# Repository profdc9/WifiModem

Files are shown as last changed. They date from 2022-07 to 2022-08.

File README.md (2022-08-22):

# WiFi Modem

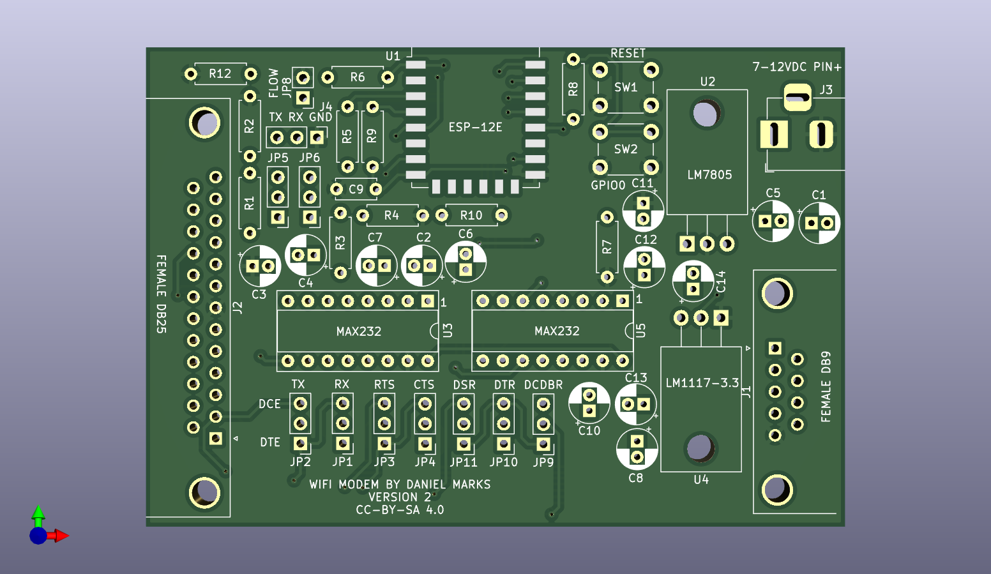
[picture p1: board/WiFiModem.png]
WiFiModem


This is a simple layout for connection a ESP12E to a serial port so that a serial to wireless gateway can be used.  It connects RTS/CTS for flow control (when supported) and has DB9 female/male and DB25 female/male connectors.  The particular gender of the connector can be mounted on the side of the board indicated by the silkscreening.  DB25 male is used to connect directly to an Apple Super Serial Card.  DB25 female is the standard connection of old-style dialup modems.  There are jumpers that swap TXD/RXD, RTS/CTS, and DTR/DSR to implement a built-in null modem changer.

There are several types of firmware that could be used on it.

https://github.com/jeelabs/esp-link

ESP Link is a firmware that enables remote access to a microcontroller or serial port through a web page or TCP port.

https://github.com/dhansel/WifiModem

https://github.com/jsalin/esp8266_modem

https://github.com/maccasoft/WifiModem/blob/master/WifiModem.ino

https://github.com/ssshake/vintage-computer-wifi-modem

https://github.com/stardot/esp8266_modem/wiki

https://github.com/RolandJuno/esp8266_modem    (implements CTS)

https://github.com/bozimmerman/Zimodem

A firmware image "zimodem.ino.nodemcu-3.4.bin" may be downloaded from:

http://subethasoftware.com/files/zimodem/

For using with ZiModem, use the following settings:

```
ATS47=5
OK
ATS49=15
OK
ATS51=13
OK
ATS53=12
OK
ATS55=14
OK
ATS57=4
OK
ATB9600
OK
AT&W
```
(default baud rate 9600 for example)

If you use the Zimodem firmware (current version 3.7.0 in that directory) that is in the "zimodem-firmware" directory, it is already compiled to point DTR/DSR/RI/RTS/CTS to the correct GPIO pins.  The default baud rate is 1200.  You can use esptool.py or the flash download tool to load it to the address 0x0000.

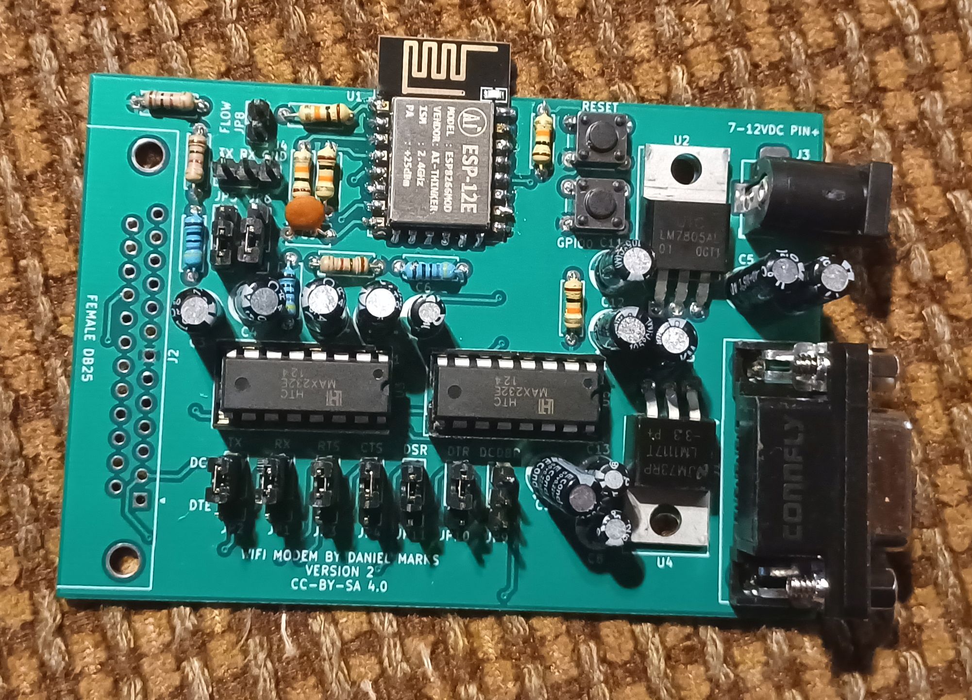
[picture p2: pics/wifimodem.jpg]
PCB


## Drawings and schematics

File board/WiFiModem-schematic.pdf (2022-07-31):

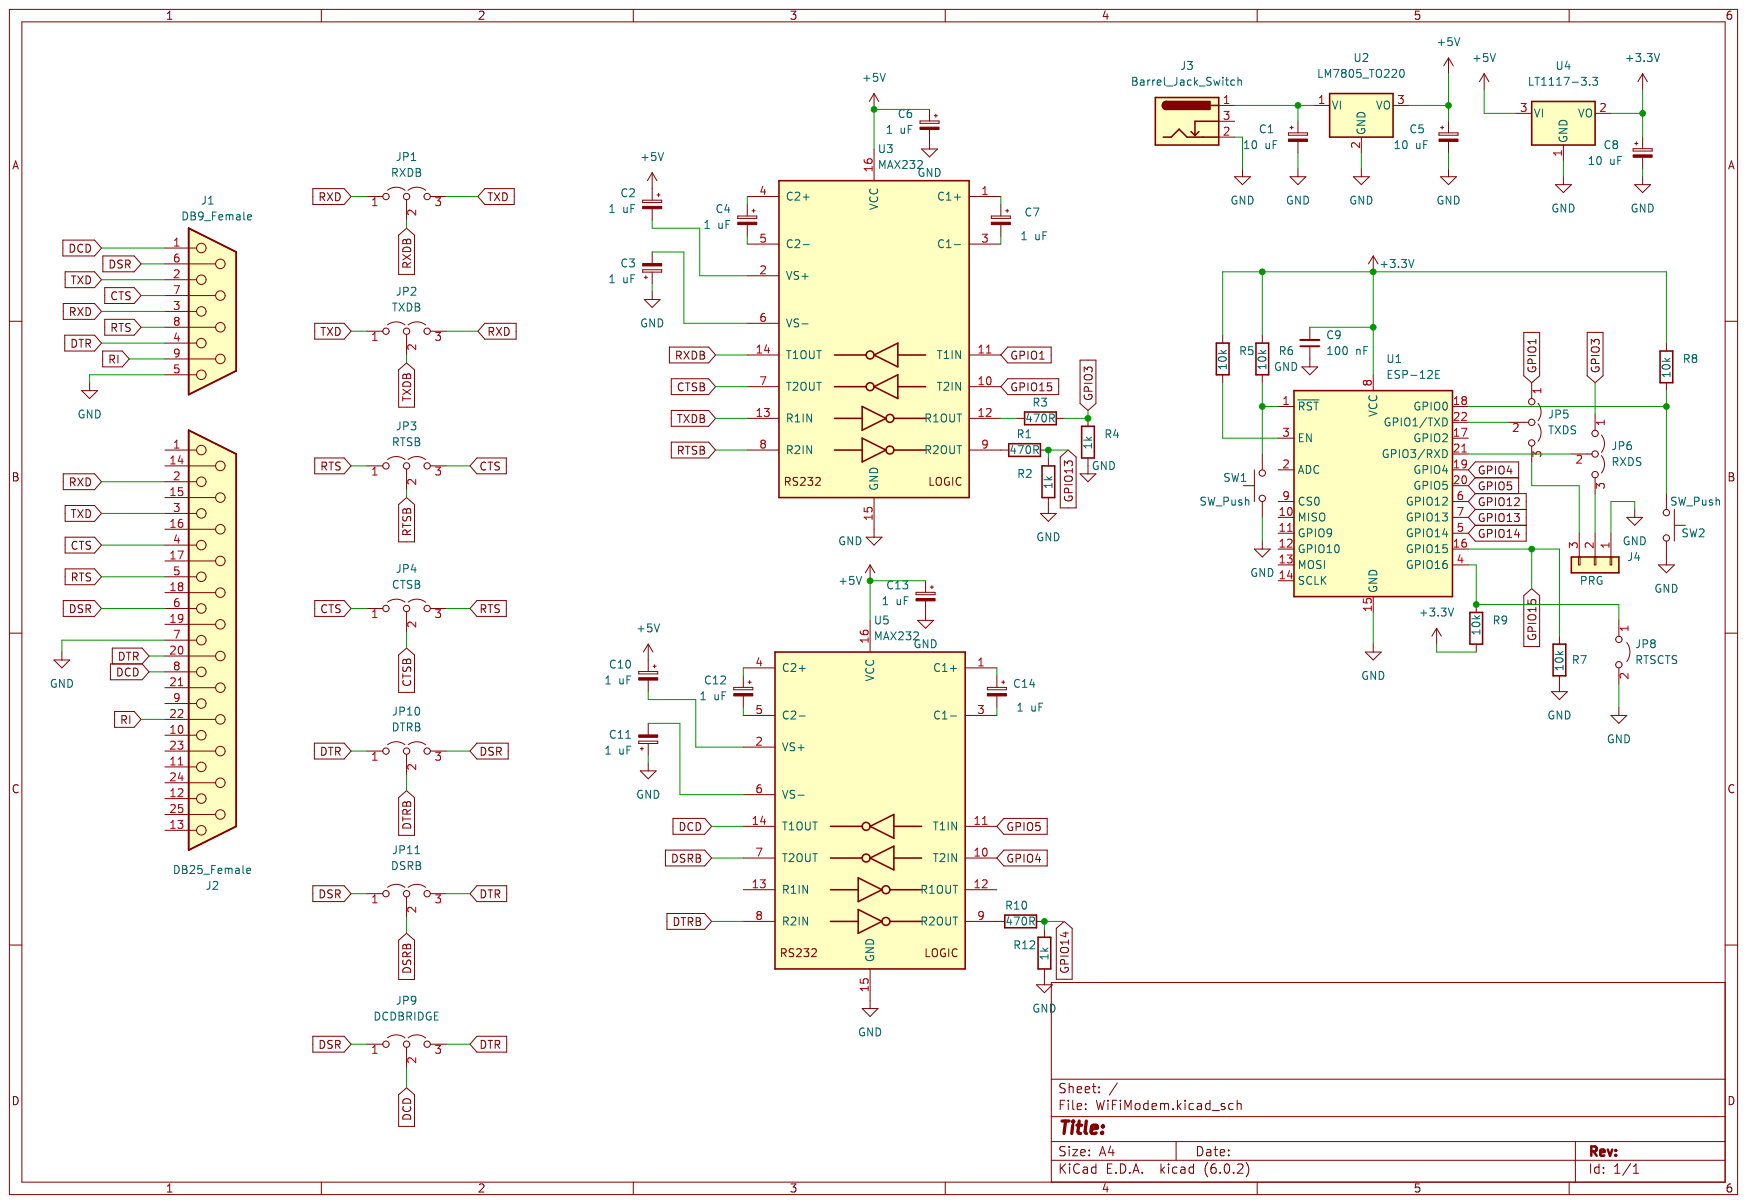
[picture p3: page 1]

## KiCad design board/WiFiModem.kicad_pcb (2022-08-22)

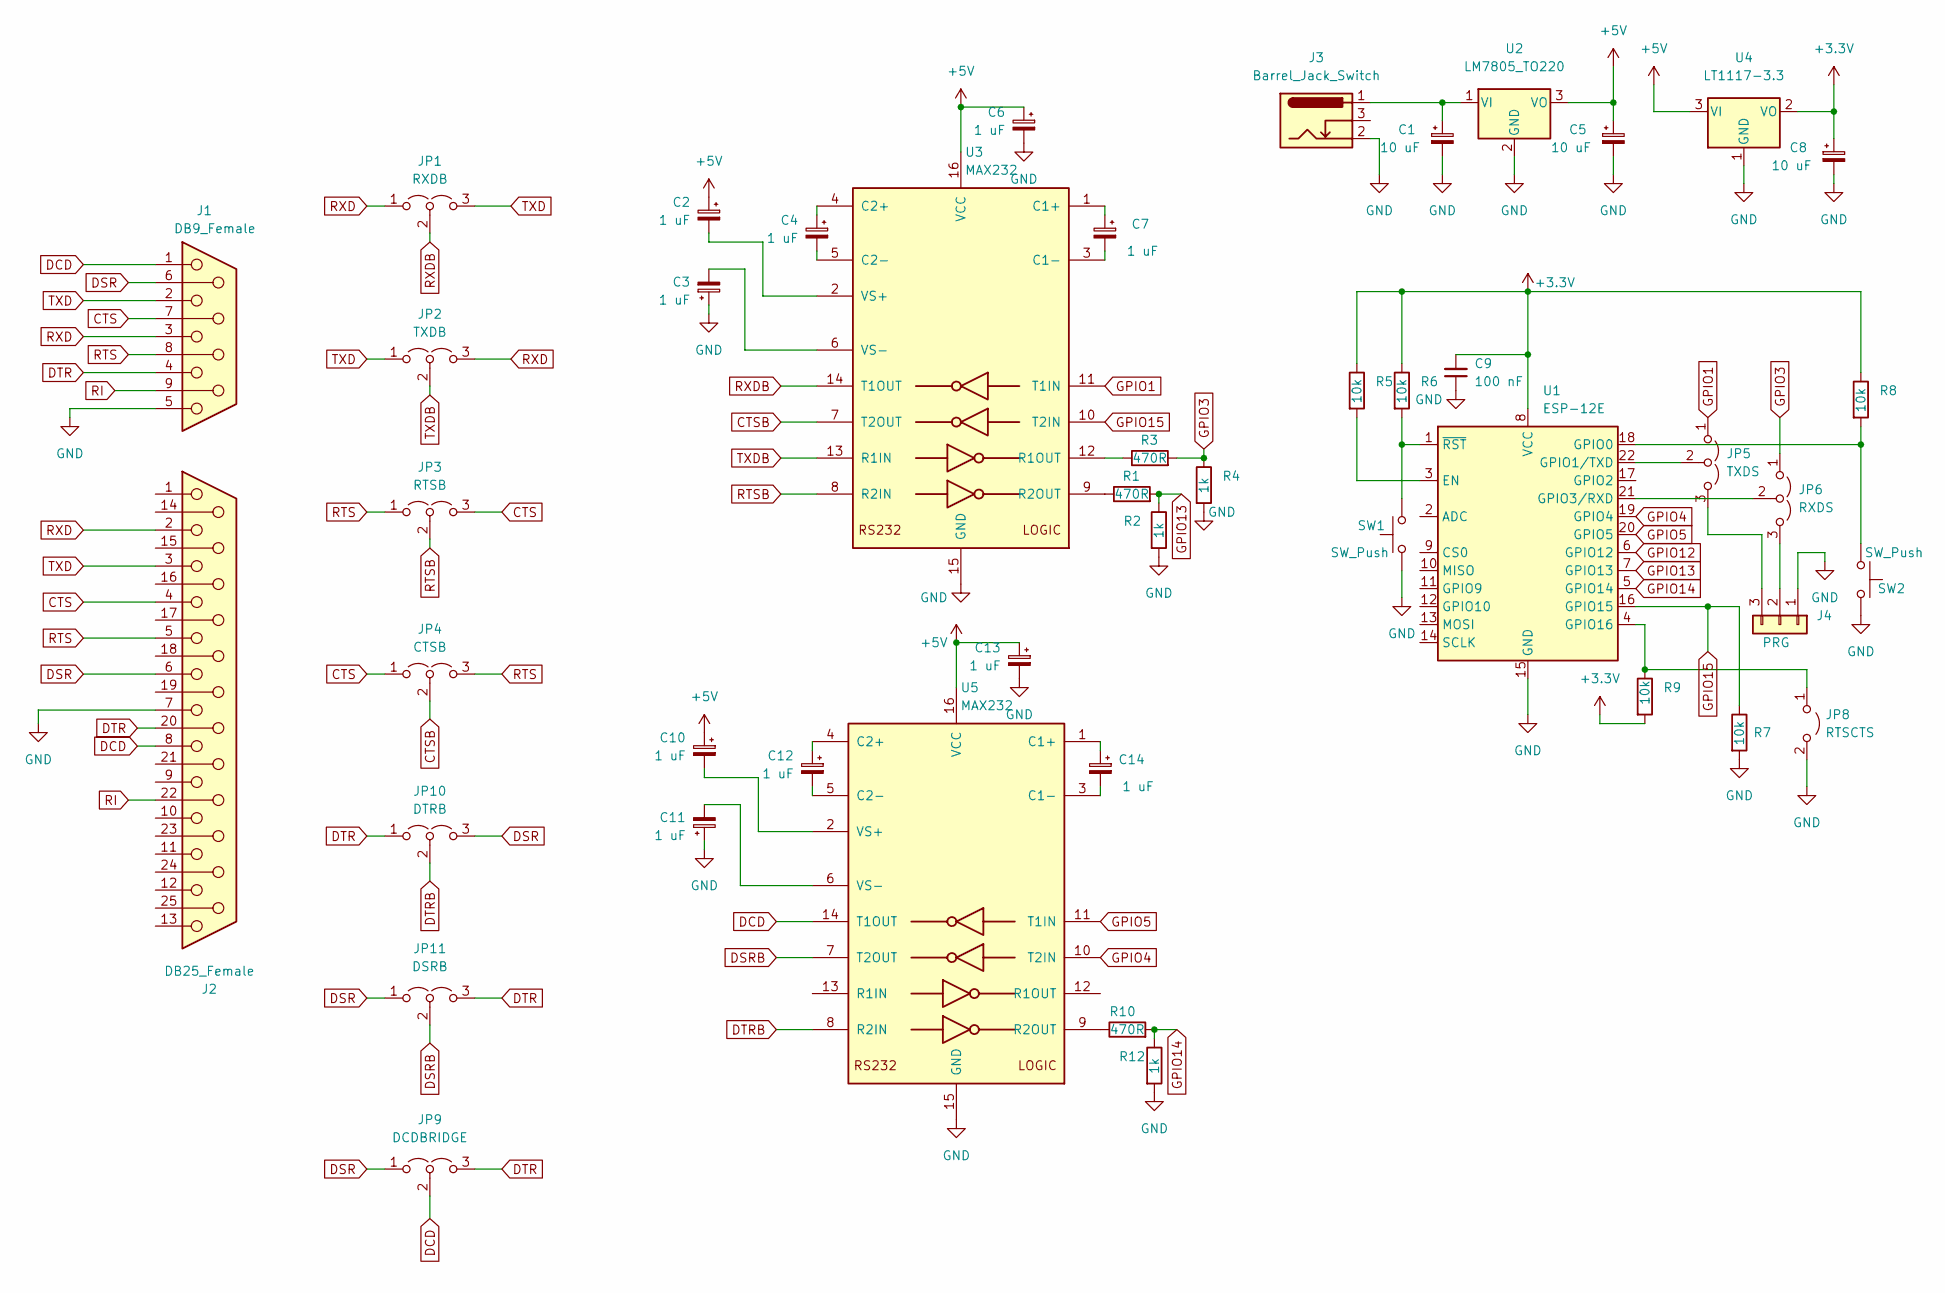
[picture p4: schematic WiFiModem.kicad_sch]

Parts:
C1, C5, C8: 10 uF; CP_Radial_D5.0mm_P2.00mm
C2, C3, C4, C6, C7, C10, C11, C12, C13, C14: 1 uF; CP_Radial_D5.0mm_P2.00mm
C9: 100 nF; C_Disc_D5.0mm_W2.5mm_P5.00mm
J1: DB9_Female; DSUB-9_Female_Horizontal_P2.77x2.84mm_EdgePinOffset4.94mm_H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
J2: DB25_Female; DSUB-25_Female_Horizontal_P2.77x2.84mm_EdgePinOffset7.70mm_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
J3: Barrel_Jack_Switch; BarrelJack_Horizontal
J4: PRG; PinHeader_1x03_P2.54mm_Vertical
JP1: RXDB; PinHeader_1x03_P2.54mm_Vertical
JP2: TXDB; PinHeader_1x03_P2.54mm_Vertical
JP3: RTSB; PinHeader_1x03_P2.54mm_Vertical
JP4: CTSB; PinHeader_1x03_P2.54mm_Vertical
JP5: TXDS; PinHeader_1x03_P2.54mm_Vertical
JP6: RXDS; PinHeader_1x03_P2.54mm_Vertical
JP8: RTSCTS; PinHeader_1x02_P2.54mm_Vertical
JP9: DCDBRIDGE; PinHeader_1x03_P2.54mm_Vertical
JP10: DTRB; PinHeader_1x03_P2.54mm_Vertical
JP11: DSRB; PinHeader_1x03_P2.54mm_Vertical
R1, R3, R10: 470R; R_Axial_DIN0207_L6.3mm_D2.5mm_P7.62mm_Horizontal
R2, R4, R12: 1k; R_Axial_DIN0207_L6.3mm_D2.5mm_P7.62mm_Horizontal
R5, R6, R7, R8, R9: 10k; R_Axial_DIN0207_L6.3mm_D2.5mm_P7.62mm_Horizontal
SW1, SW2: SW_Push; SW_PUSH_6mm
U1: ESP-12E
U2: LM7805_TO220; TO-220-3_Horizontal_TabDown
U3, U5: MAX232; DIP-16_W7.62mm_Socket
U4: LT1117-3.3; TO-220-3_Horizontal_TabDown

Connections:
+3V3: C8.1, C9.2, R5.1, R6.1, R8.1, R9.2, U1.8 (VCC), U4.2 (VO)
+5V: C2.1, C5.1, C6.1, C10.1, C13.1, U2.3 (VO), U3.16 (VCC), U4.3 (VI), U5.16 (VCC)
CTS: J1.7, J2.4, JP3.3 (B), JP4.1 (A)
CTSB: JP4.2 (C), U3.7 (T2OUT)
DCD: J1.1, J2.8, JP9.2 (C), U5.14 (T1OUT)
DSR: J1.6, J2.6, JP9.1 (A), JP10.3 (B), JP11.1 (A)
DSRB: JP11.2 (C), U5.7 (T2OUT)
DTR: J1.4, J2.20, JP9.3 (B), JP10.1 (A), JP11.3 (B)
DTRB: JP10.2 (C), U5.8 (R2IN)
GND: C1.2, C3.1, C5.2, C6.2, C8.2, C9.1, C11.1, C13.2, J1.5, J2.7, J3.2, J4.1, JP8.2 (B), R2.2, R4.2, R7.2, R12.2, SW1.1, SW2.2, U1.15 (GND), U2.2 (GND), U3.15 (GND), U4.1 (GND), U5.15 (GND)
GPIO1: JP5.1 (A), U3.11 (T1IN)
GPIO3: JP6.1 (A), R3.2, R4.1
GPIO4: U1.19 (GPIO4), U5.10 (T2IN)
GPIO5: U1.20 (GPIO5), U5.11 (T1IN)
GPIO12: U1.6 (GPIO12)
GPIO13: R1.2, R2.1, U1.7 (GPIO13)
GPIO14: R10.2, R12.1, U1.5 (GPIO14)
GPIO15: R7.1, U1.16 (GPIO15), U3.10 (T2IN)
unnamed: C1.1, J3.1, U2.1 (VI)
unnamed: C2.2, U3.2 (VS+)
unnamed: C3.2, U3.6 (VS-)
unnamed: C4.1, U3.4 (C2+)
unnamed: C4.2, U3.5 (C2-)
unnamed: C7.1, U3.1 (C1+)
unnamed: C7.2, U3.3 (C1-)
unnamed: C10.2, U5.2 (VS+)
unnamed: C11.2, U5.6 (VS-)
unnamed: C12.1, U5.4 (C2+)
unnamed: C12.2, U5.5 (C2-)
unnamed: C14.1, U5.1 (C1+)
unnamed: C14.2, U5.3 (C1-)
unnamed: J4.2, JP6.3 (B)
unnamed: J4.3, JP5.3 (B)
unnamed: JP5.2 (C), U1.22 (GPIO1/TXD)
unnamed: JP6.2 (C), U1.21 (GPIO3/RXD)
unnamed: JP8.1 (A), R9.1, U1.4 (GPIO16)
unnamed: R1.1, U3.9 (R2OUT)
unnamed: R3.1, U3.12 (R1OUT)
unnamed: R5.2, U1.3 (EN)
unnamed: R6.2, SW1.2, U1.1 (~RST)
unnamed: R8.2, SW2.1, U1.18 (GPIO0)
unnamed: R10.1, U5.9 (R2OUT)
RI: J1.9, J2.22
RTS: J1.8, J2.5, JP3.1 (A), JP4.3 (B)
RTSB: JP3.2 (C), U3.8 (R2IN)
RXD: J1.3, J2.2, JP1.1 (A), JP2.3 (B)
RXDB: JP1.2 (C), U3.14 (T1OUT)
TXD: J1.2, J2.3, JP1.3 (B), JP2.1 (A)
TXDB: JP2.2 (C), U3.13 (R1IN)

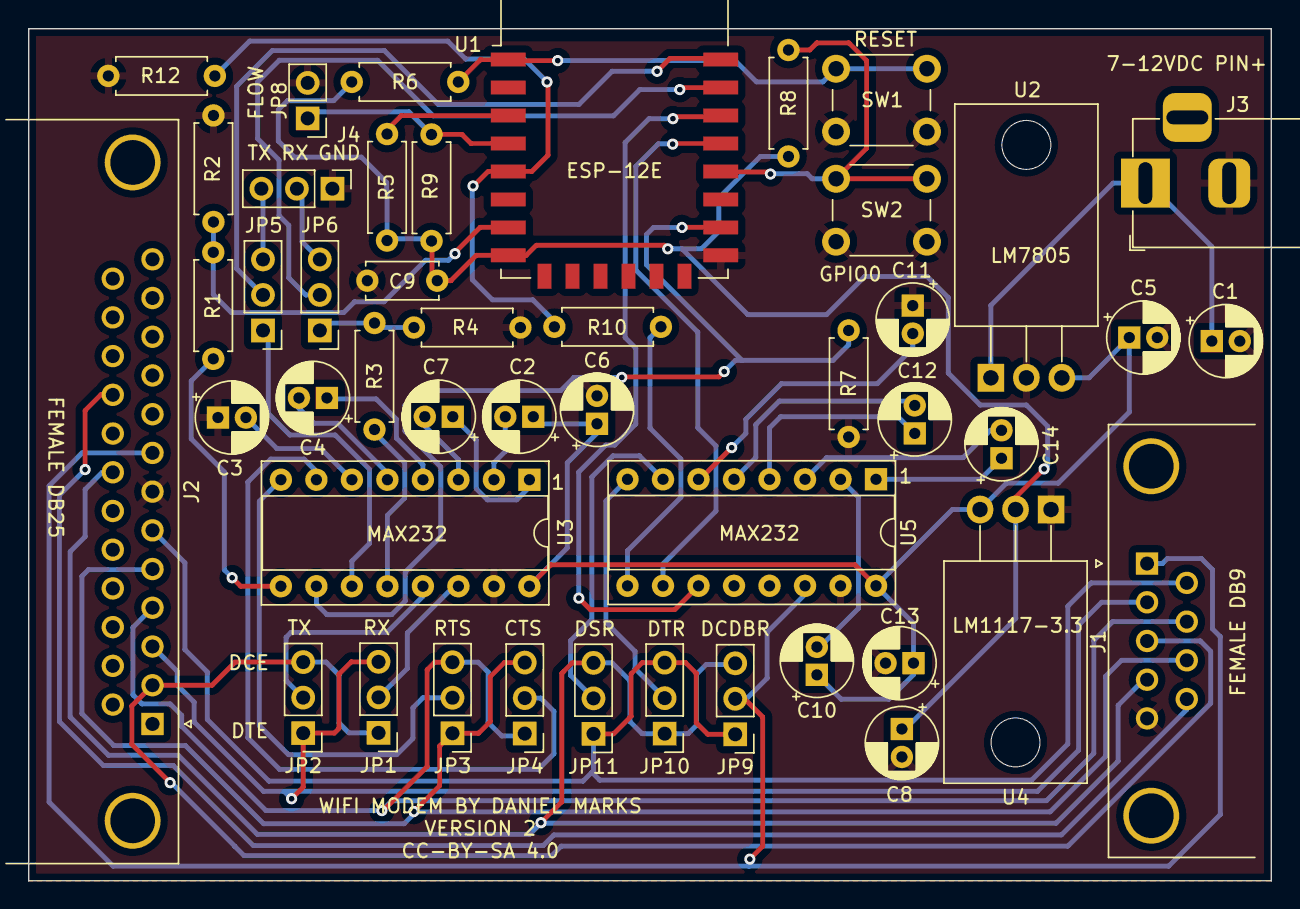
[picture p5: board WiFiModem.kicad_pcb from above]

Board: 2 copper layers, 88.9 x 61.0 mm, 46 parts (0 on the bottom side), 48 nets.

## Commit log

2022-07-06 swap RTS and CTS
    [WiFiModem-B_Cu.gbr, WiFiModem-B_Mask.gbr, WiFiModem-B_Paste.gbr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]
2022-07-06 Added flow control enable GPIO
    [WiFiModem-B_Cu.gbr, WiFiModem-B_Mask.gbr, WiFiModem-B_Paste.gbr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]
2022-07-09 Added all of the other control signals
    [WiFiModem-B_Cu.gbr, WiFiModem-B_Mask.gbr, WiFiModem-B_Paste.gbr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]
2022-07-10 Changed from DB25 male to DB25 female
    [WiFiModem-B_Cu.gbr, WiFiModem-B_Mask.gbr, WiFiModem-B_Paste.gbr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]
2022-07-11 Added silkscreening to indicate male/female sides
    [WiFiModem-B_Cu.gbr, WiFiModem-B_Mask.gbr, WiFiModem-B_Paste.gbr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]
2022-07-24 Fixed GPIO15 booting issue, changed DCD/DSR/DTR jumper
    [WiFiModem-B_Cu.gbr, WiFiModem-B_Mask.gbr, WiFiModem-B_Paste.gbr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]
2022-07-31 Fixed DCD and DB25 pinouts
    [WiFiModem-B_Cu.gbr, WiFiModem-B_Mask.gbr, WiFiModem-B_Paste.gbr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]
2022-08-01 Moved around some traces
    [WiFiModem-B_Cu.gbr, WiFiModem-B_Mask.gbr, WiFiModem-B_Paste.gbr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]
2022-08-22 Added picture of completed boarD
    [WiFiModem-B_Cu.gbr, WiFiModem-B_Mask.gbr, WiFiModem-B_Paste.gbr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]

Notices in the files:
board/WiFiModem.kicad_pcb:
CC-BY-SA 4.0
